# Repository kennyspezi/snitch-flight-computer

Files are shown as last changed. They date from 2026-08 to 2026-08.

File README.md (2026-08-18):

# Flight Compute Unit (FCU)
For future UAV and upcoming Omnimouse build (continuation of Micromouse)

## Schematics
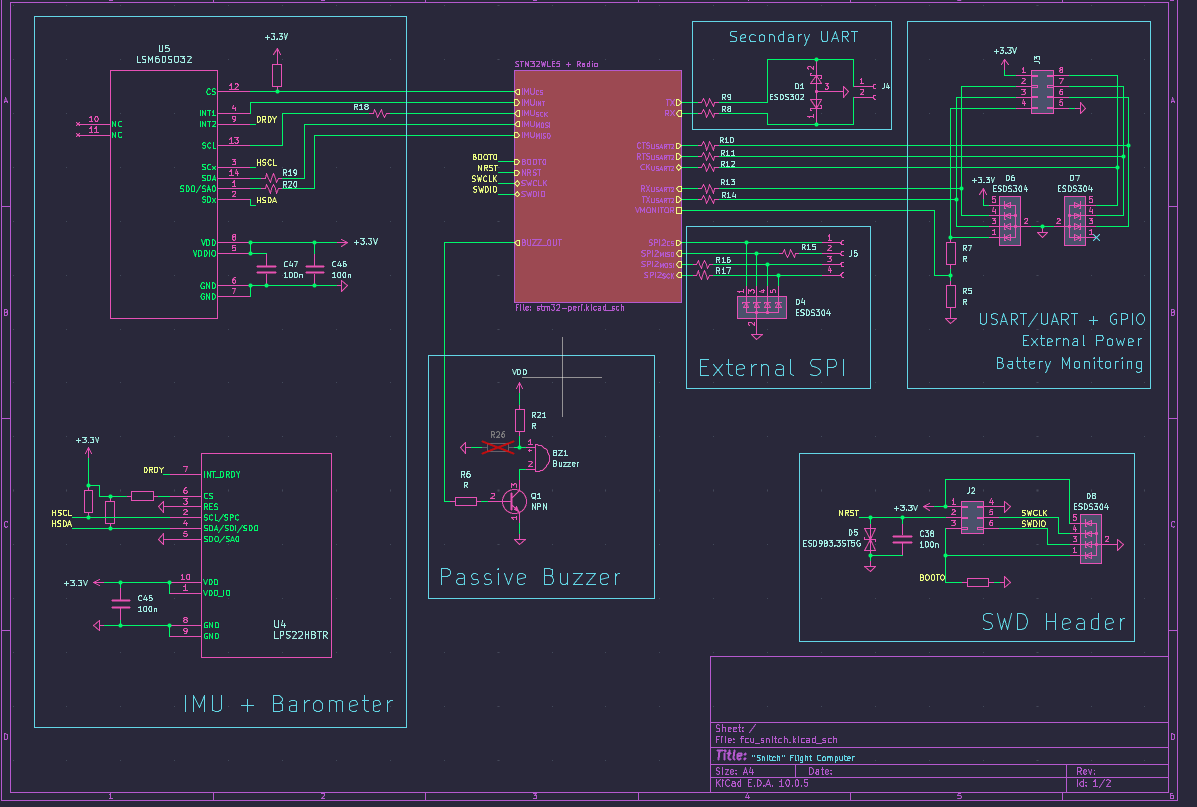
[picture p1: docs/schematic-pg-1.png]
Pg 1

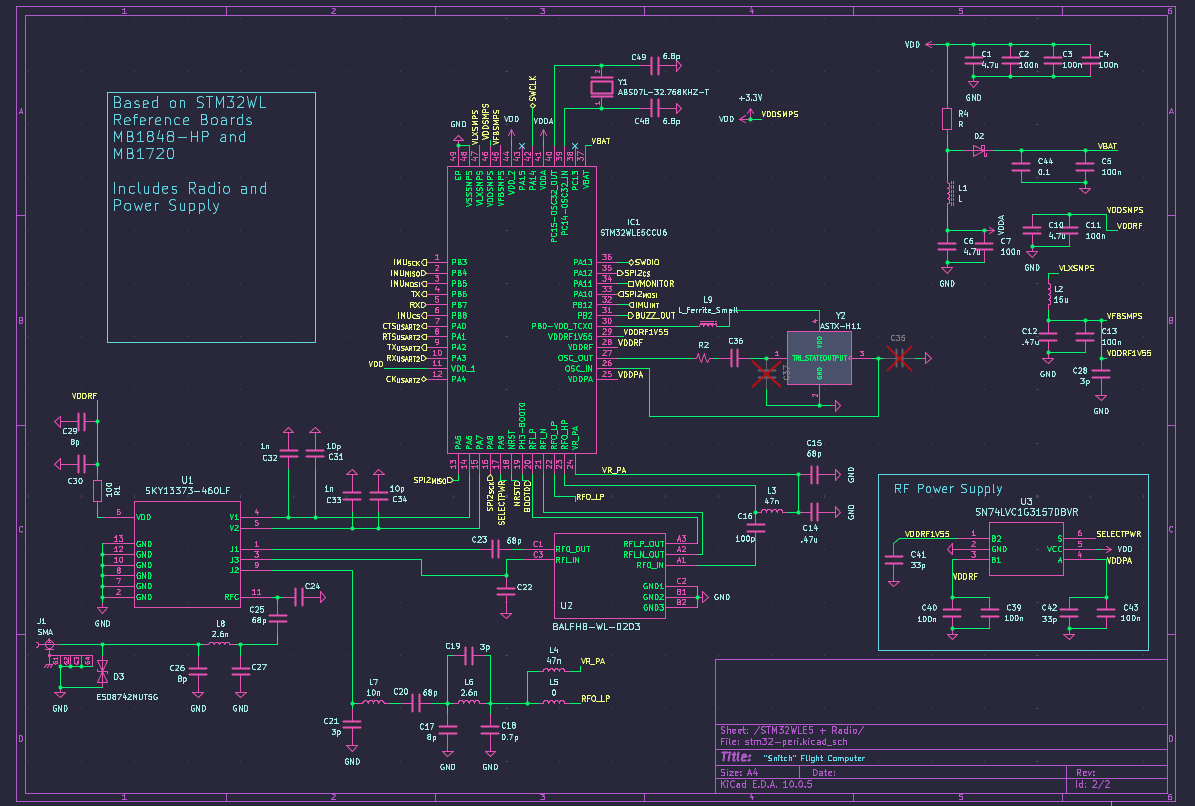
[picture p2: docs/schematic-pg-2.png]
Pg 2


## PCB (as of 08/18/2026)
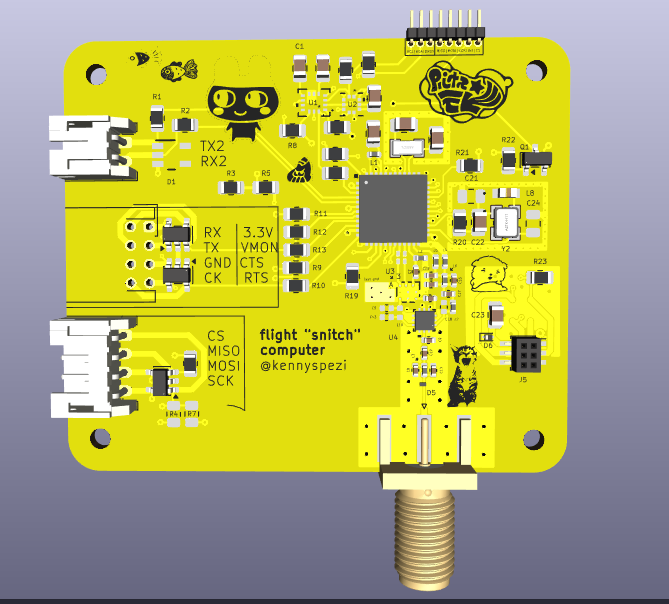
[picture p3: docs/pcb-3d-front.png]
3D Front

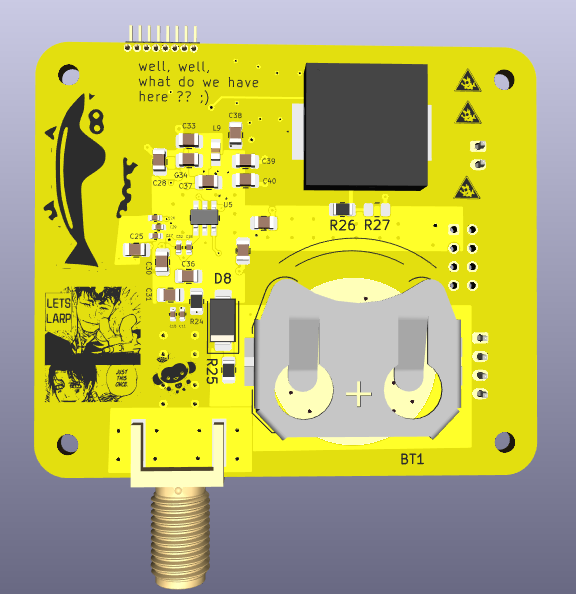
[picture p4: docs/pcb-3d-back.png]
3D Back


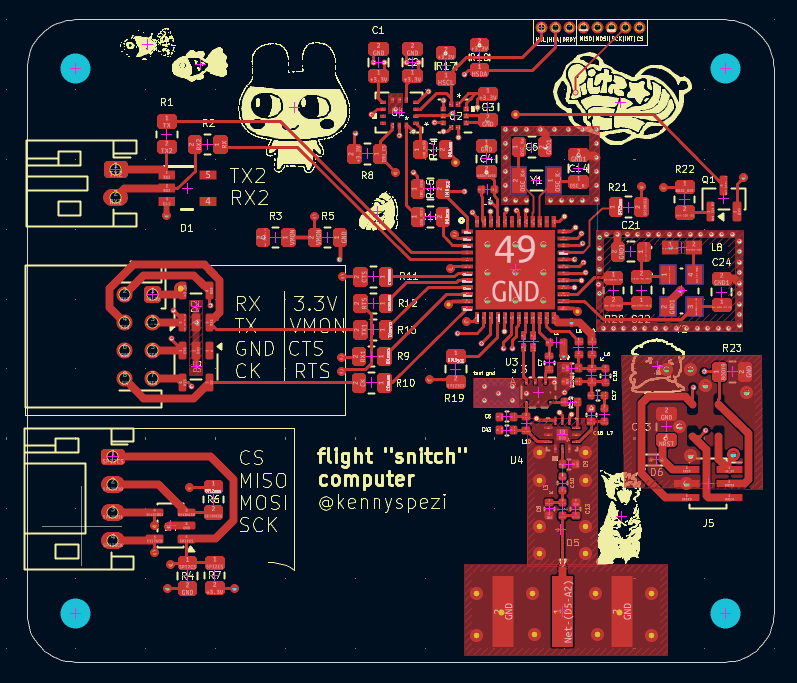
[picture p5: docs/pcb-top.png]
Top Layer

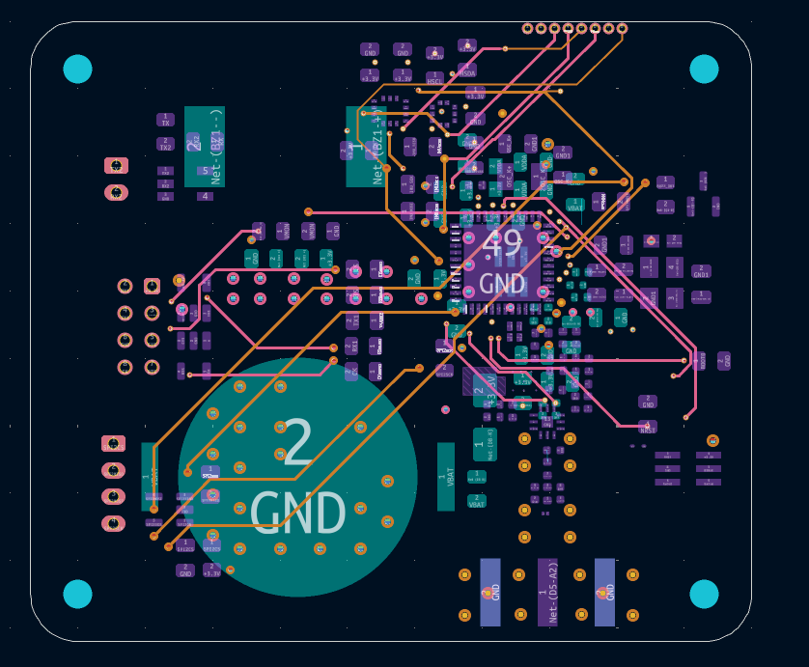
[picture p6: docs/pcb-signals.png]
Signals

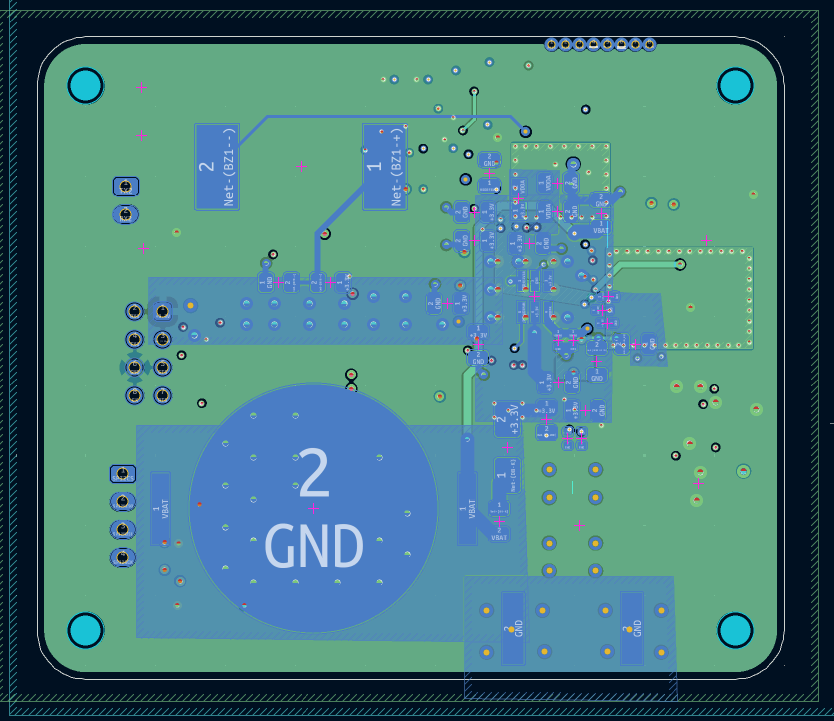
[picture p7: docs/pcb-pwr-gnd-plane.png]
Power + GND Distribution

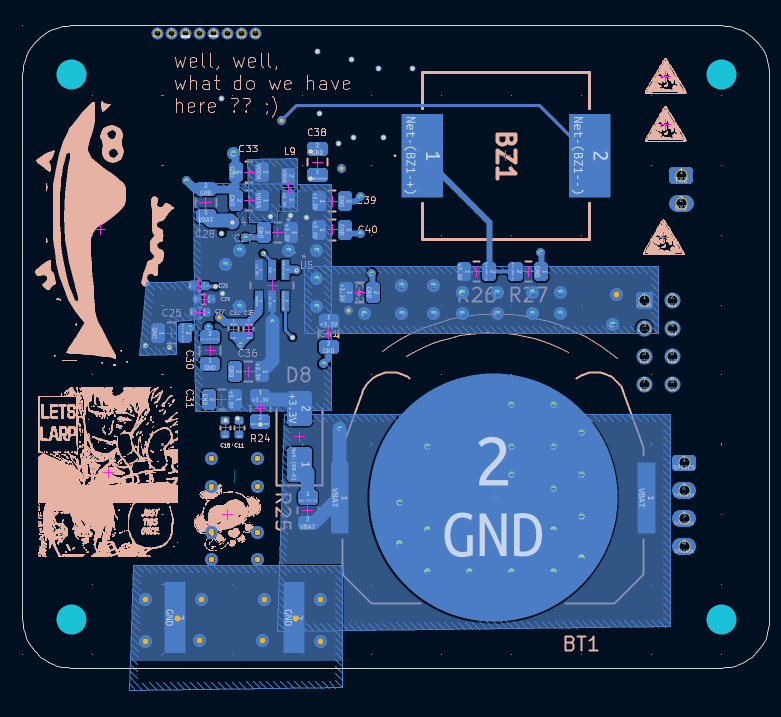
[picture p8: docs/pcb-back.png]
Bottom Layer


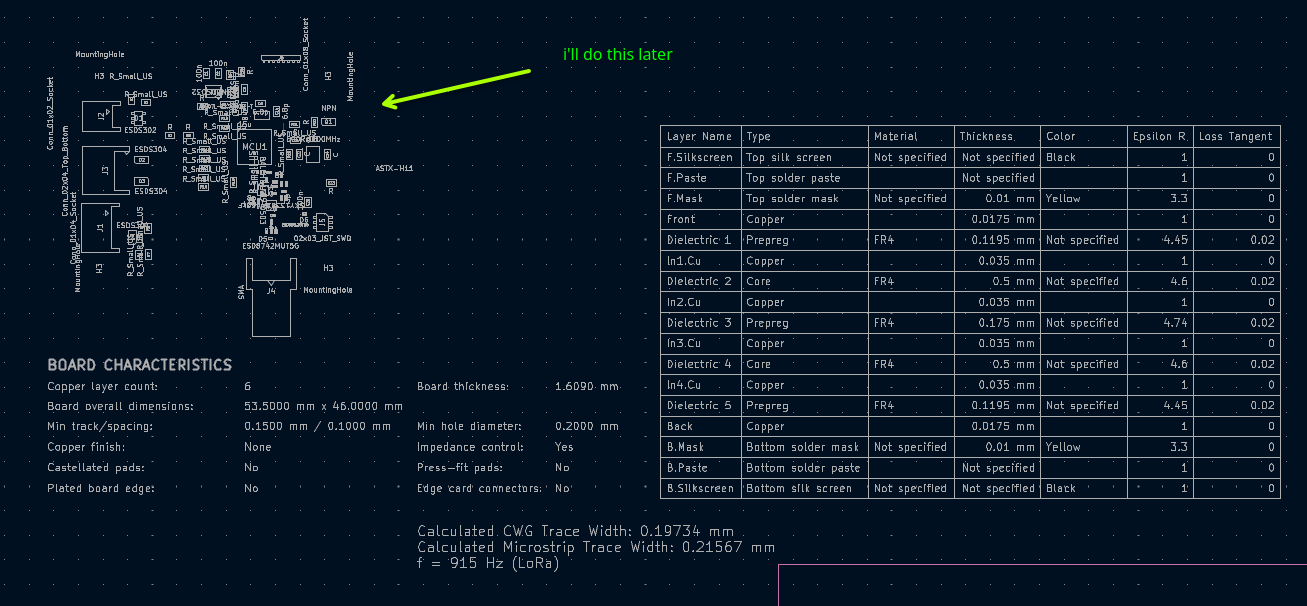
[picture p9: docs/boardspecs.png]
BoardSpecs


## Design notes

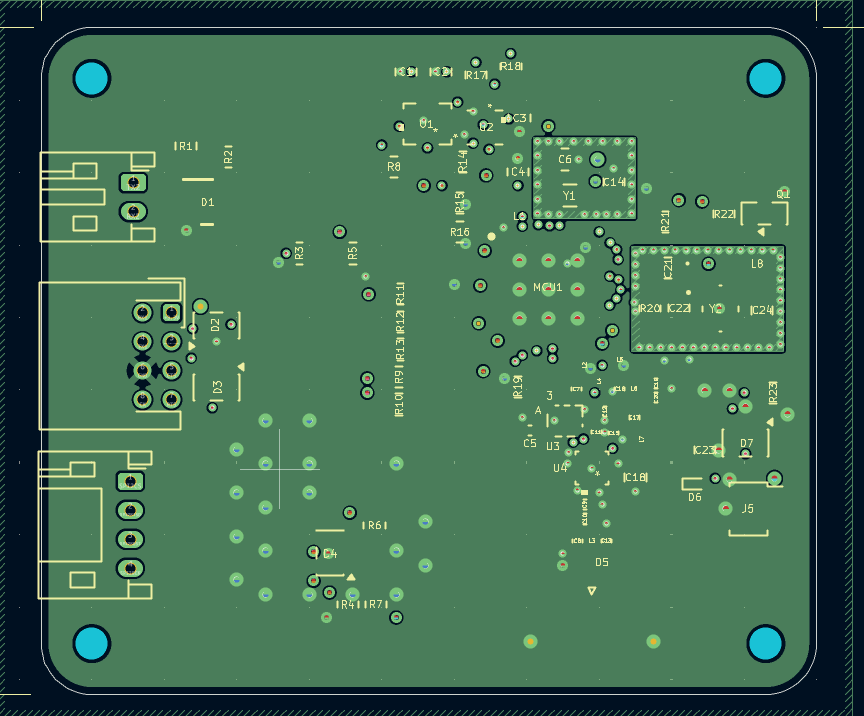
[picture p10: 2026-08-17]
docs/pcb-gnd.png

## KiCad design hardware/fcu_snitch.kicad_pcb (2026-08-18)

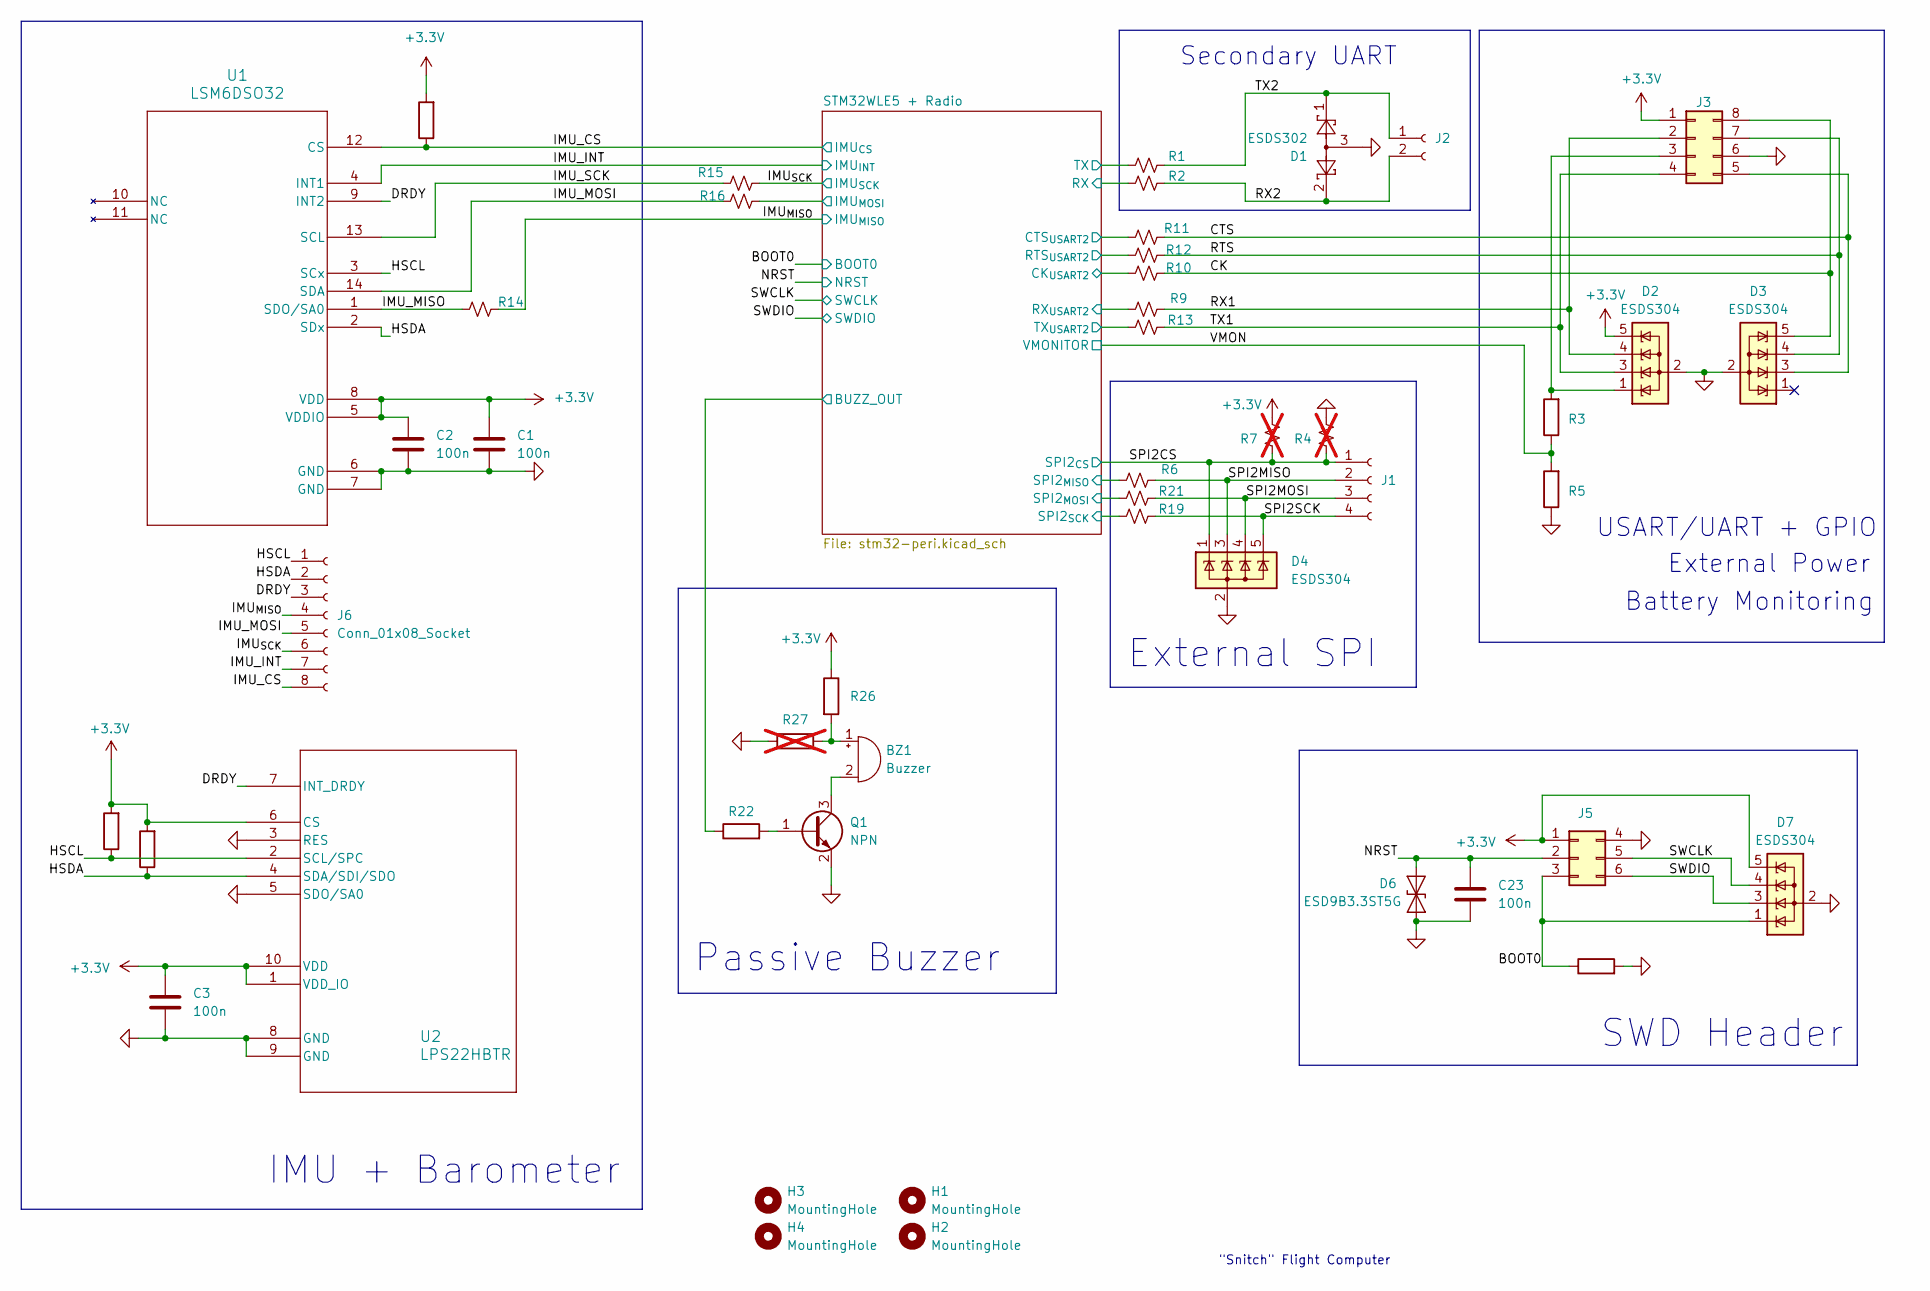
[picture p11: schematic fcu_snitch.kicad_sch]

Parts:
BZ1: Buzzer; CPT120303SMTTR
C1, C2, C3, C23: 100n; C_0805_2012Metric
D1: ESDS302; DBV0005A_M
D2, D3, D4, D7: ESDS304; SOT-23-5
D6: ESD9B3.3ST5G; D_SOD-923
H1, H2, H3, H4: MountingHole; MountingHole_2.2mm_M2
J1: Conn_01x04_Socket; JST_PH_S4B-PH-K_1x04_P2.00mm_Horizontal
J2: Conn_01x02_Socket; JST_PH_S2B-PH-K_1x02_P2.00mm_Horizontal
J3: Conn_02x04_Top_Bottom; JST_PHD_S8B-PHDSS_2x04_P2.00mm_Horizontal
J5: 02x03_JST_SWD; PinSocket_2x03_P1.00mm_Vertical_SMD
J6: Conn_01x08_Socket; PinHeader_1x08_P1.00mm_Horizontal
Q1: NPN; SOT-23
R1, R2, R6, R9, R10, R11, R12, R13, R14, R15, R16, R19, R21: R_Small_US; R_0805_2012Metric
R3, R5, R8, R17, R18, R22, R23, R26: R; R_0805_2012Metric
R4, R7: R_Small_US; R_0805_2012Metric; not fitted
R27: R; R_0805_2012Metric; not fitted
U1: LSM6DSO32; LGA-14L_2P5X3X0P83_STM-L
U2: LPS22HBTR; HLGA10_2X2_STM-L

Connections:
+3.3V: C1.1, C2.1, C3.1, D2.5 (K), D7.5 (K), J3.1, J5.1, R7.2, R8.2, R17.2, R18.2, R26.1, U1.5 (VDDIO), U1.8 (VDD), U2.1 (VDD_IO), U2.6 (CS), U2.10 (VDD); also elsewhere on the board
/BOOT0: D7.1 (K), J5.3, R23.1; also elsewhere on the board
/CK: D3.5 (K), J3.8, R10.2
/CTS: D3.3 (K), J3.5, R11.2
/DRDY: J6.3, U1.9 (INT2), U2.7 (INT_DRDY)
/HSCL: J6.1, R17.1, U1.3 (SCx), U2.2 (SCL/SPC)
/HSDA: J6.2, R18.1, U1.2 (SDx), U2.4 (SDA/SDI/SDO)
/IMU_CS: J6.8, R8.1, U1.12 (CS); also elsewhere on the board
/IMU_INT: J6.7, U1.4 (INT1); also elsewhere on the board
/IMU_MISO: R14.1, U1.1 (SDO/SA0)
/IMU_MOSI: J6.5, R16.1, U1.14 (SDA)
/IMU_SCK: R15.1, U1.13 (SCL)
/IMU_{MISO}: J6.4, R14.2; also elsewhere on the board
/IMU_{SCK}: J6.6, R15.2; also elsewhere on the board
/NRST: C23.1, D6.2 (A2), J5.2; also elsewhere on the board
/RTS: D3.4 (K), J3.7, R12.2
/RX1: D2.4 (K), J3.2, R9.2
/RX2: D1.2, J2.2, R2.2
/SPI2CS: D4.1 (K), J1.1, R4.1, R7.1; also elsewhere on the board
/SPI2MISO: D4.3 (K), J1.2, R6.2
/SPI2MOSI: D4.4 (K), J1.3, R21.2
/SPI2SCK: D4.5 (K), J1.4, R19.2
/STM32WLE5 + Radio/BUZZ_OUT: R22.1; also elsewhere on the board
/STM32WLE5 + Radio/CK_{USART2}: R10.1; also elsewhere on the board
/STM32WLE5 + Radio/CTS_{USART2}: R11.1; also elsewhere on the board
/STM32WLE5 + Radio/IMU_{MOSI}: R16.2; also elsewhere on the board
/STM32WLE5 + Radio/RTS_{USART2}: R12.1; also elsewhere on the board
/STM32WLE5 + Radio/RX: R2.1; also elsewhere on the board
/STM32WLE5 + Radio/RX_{USART2}: R9.1; also elsewhere on the board
/STM32WLE5 + Radio/SPI2_{MISO}: R6.1; also elsewhere on the board
/STM32WLE5 + Radio/SPI2_{MOSI}: R21.1; also elsewhere on the board
/STM32WLE5 + Radio/SPI2_{SCK}: R19.1; also elsewhere on the board
/STM32WLE5 + Radio/TX: R1.1; also elsewhere on the board
/STM32WLE5 + Radio/TX_{USART2}: R13.1; also elsewhere on the board
/SWCLK: D7.4 (K), J5.5; also elsewhere on the board
/SWDIO: D7.3 (K), J5.6; also elsewhere on the board
/TX1: D2.3 (K), J3.4, R13.2
/TX2: D1.1, J2.1, R1.2
/VMON: R3.1, R5.2; also elsewhere on the board
GND: C1.2, C2.2, C3.2, C23.2, D1.3, D2.2 (A), D3.2 (A), D4.2 (A), D6.1 (A1), D7.2 (A), J3.6, J5.4, Q1.2 (E), R4.2, R5.1, R23.2, R27.1, U1.6 (GND), U1.7 (GND), U2.3 (RES), U2.5 (SDO/SA0), U2.8 (GND), U2.9 (GND); also elsewhere on the board
unnamed: BZ1.1 (+), R26.2, R27.2
unnamed: BZ1.2 (-), Q1.3 (C)
unnamed: D2.1 (K), J3.3, R3.2
unnamed: Q1.1 (B), R22.2

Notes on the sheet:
External SPI
Secondary UART
Battery Monitoring
IMU + Barometer
USART/UART + GPIO
SWD Header
External Power
"Snitch" Flight Computer
Passive Buzzer

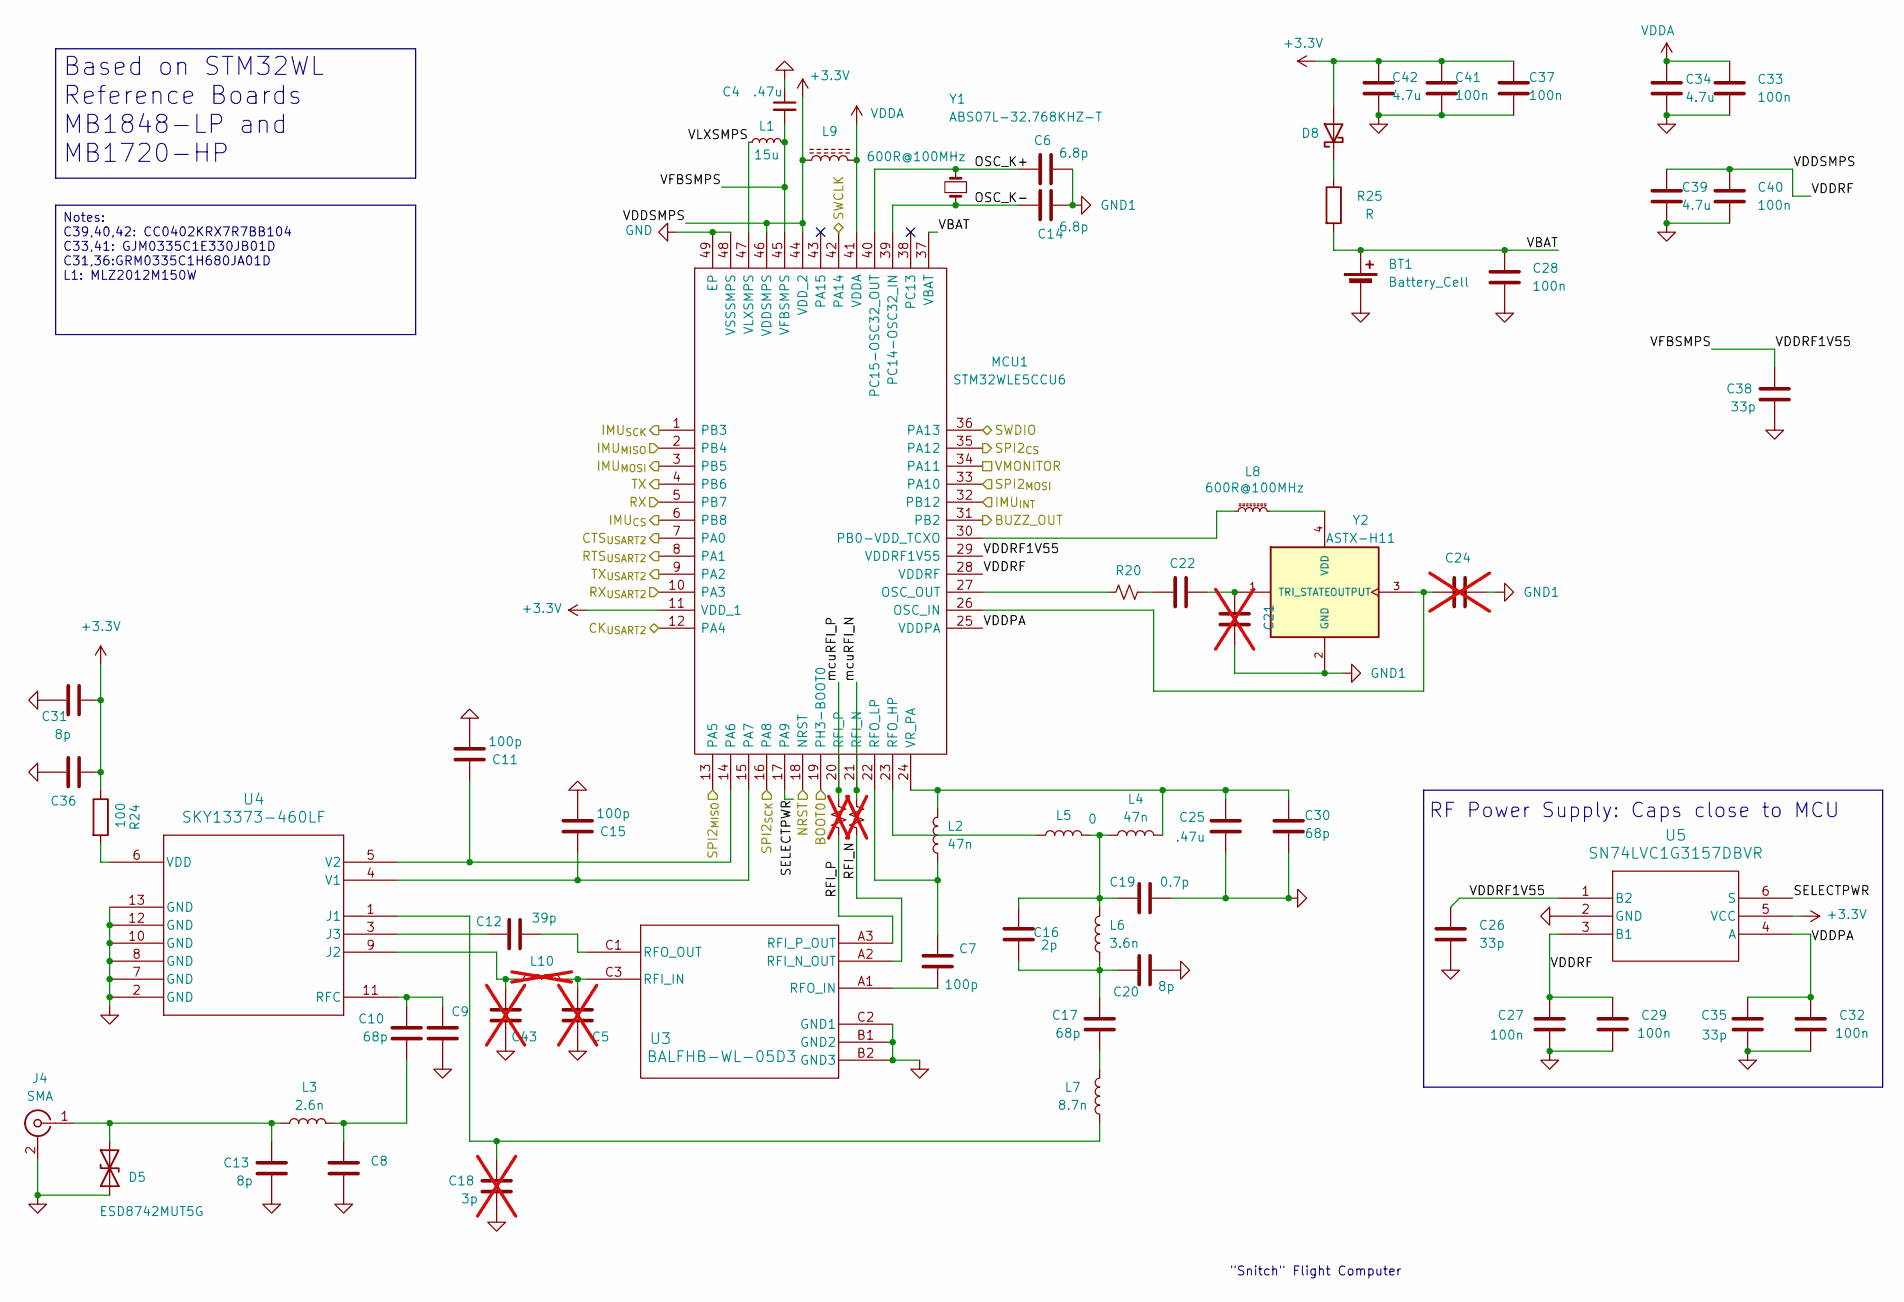
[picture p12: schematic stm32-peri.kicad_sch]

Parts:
BT1: Battery_Cell; BatteryHolder_Keystone_3034_1x20mm
C4, C25: .47u; C_0805_2012Metric
C5: 100p; C_0402_1005Metric; not fitted
C6, C14: 6.8p; C_0805_2012Metric
C7, C11, C15: 100p; C_0402_1005Metric
C8, C9: C_0402_1005Metric
C10, C17: 68p; C_0402_1005Metric
C12: 39p; C_0402_1005Metric
C13, C20: 8p; C_0402_1005Metric
C16: 2p; C_0402_1005Metric
C18: 3p; C_0402_1005Metric; not fitted
C19: 0.7p; C_0402_1005Metric
C21, C24: C; C_0805_2012Metric; not fitted
C22: C; C_0805_2012Metric
C26, C35: 33p; C_0402_1005Metric
C27, C29, C32: 100n; C_0402_1005Metric
C28, C33, C37, C40, C41: 100n; C_0805_2012Metric
C30: 68p; C_0805_2012Metric
C31: 8p; C_0805_2012Metric
C34, C39, C42: 4.7u; C_0805_2012Metric
C36: C_0805_2012Metric
C38: 33p; C_0805_2012Metric
C43: 8p; C_0402_1005Metric; not fitted
D5: ESD8742MUT5G; X3DFN2_ONS
D8: D_Schottky; D_SMA
J4: SMA; SMA_Amphenol_132289_EdgeMount
L1: 15u; L_0402_1005Metric
L2, L4: 47n; L_0402_1005Metric
L3: 2.6n; L_0402_1005Metric
L5: 0; L_0402_1005Metric
L6: 3.6n; L_0402_1005Metric
L7: 8.7n; L_0402_1005Metric
L8, L9: 600R@100MHz; IND_BLM18KG601SN1D_MUR-M
L10: 3.6n; L_0402_1005Metric; not fitted
MCU1: STM32WLE5CCU6; QFN50P700X700X60-49N-D; Mouser Part Number 511-STM32WLE5CCU6
R20: R_Small_US; R_0805_2012Metric
R24: 100; R_0805_2012Metric
R25: R; R_0805_2012Metric
R28, R29: R_Small_US; R_0201_0603Metric_Pad0.64x0.40mm_HandSolder; not fitted
U3: BALFHB-WL-05D3; BGA8_BALFHB_STM
U4: SKY13373-460LF; SKY13373-460LF_SKY
U5: SN74LVC1G3157DBVR; DBV6
Y1: ABS07L-32.768KHZ-T; XTAL_ABS07L-32.768KHZ-T; PARTREV 02.07.13
Y2: ASTX-H11; XTAL_ASTX-H11-32.000MHZ-I25-T; PARTREV 05.13.15

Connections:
+3.3V: C27.1, C29.1, C31.1, C36.1, C37.1, C39.1, C40.1, C41.1, C42.1, D8.2 (A), L9.1, MCU1.11 (VDD_1), MCU1.28 (VDDRF), MCU1.44 (VDD_2), MCU1.46 (VDDSMPS), R24.1, U5.3 (B1), U5.5 (VCC); also elsewhere on the board
/BOOT0: MCU1.19 (PH3-BOOT0); also elsewhere on the board
/IMU_CS: MCU1.6 (PB8); also elsewhere on the board
/IMU_INT: MCU1.32 (PB12); also elsewhere on the board
/IMU_{MISO}: MCU1.2 (PB4); also elsewhere on the board
/IMU_{SCK}: MCU1.1 (PB3); also elsewhere on the board
/NRST: MCU1.18 (NRST); also elsewhere on the board
/SPI2CS: MCU1.35 (PA12); also elsewhere on the board
/STM32WLE5 + Radio/BUZZ_OUT: MCU1.31 (PB2); also elsewhere on the board
/STM32WLE5 + Radio/CK_{USART2}: MCU1.12 (PA4); also elsewhere on the board
/STM32WLE5 + Radio/CTS_{USART2}: MCU1.7 (PA0); also elsewhere on the board
/STM32WLE5 + Radio/IMU_{MOSI}: MCU1.3 (PB5); also elsewhere on the board
/STM32WLE5 + Radio/OSC_K+: C6.1, MCU1.40 (PC15-OSC32_OUT), Y1.2
/STM32WLE5 + Radio/OSC_K-: C14.1, MCU1.39 (PC14-OSC32_IN), Y1.1
/STM32WLE5 + Radio/RFI_N: R29.2, U3.A2 (RFI_N_OUT)
/STM32WLE5 + Radio/RFI_P: R28.2, U3.A3 (RFI_P_OUT)
/STM32WLE5 + Radio/RTS_{USART2}: MCU1.8 (PA1); also elsewhere on the board
/STM32WLE5 + Radio/RX: MCU1.5 (PB7); also elsewhere on the board
/STM32WLE5 + Radio/RX_{USART2}: MCU1.10 (PA3); also elsewhere on the board
/STM32WLE5 + Radio/SELECTPWR: MCU1.17 (PA9), U5.6 (S)
/STM32WLE5 + Radio/SPI2_{MISO}: MCU1.13 (PA5); also elsewhere on the board
/STM32WLE5 + Radio/SPI2_{MOSI}: MCU1.33 (PA10); also elsewhere on the board
/STM32WLE5 + Radio/SPI2_{SCK}: MCU1.16 (PA8); also elsewhere on the board
/STM32WLE5 + Radio/TX: MCU1.4 (PB6); also elsewhere on the board
/STM32WLE5 + Radio/TX_{USART2}: MCU1.9 (PA2); also elsewhere on the board
/STM32WLE5 + Radio/VBAT: BT1.1 (+), C28.1, MCU1.37 (VBAT), R25.2
/STM32WLE5 + Radio/VDDPA: C32.1, C35.1, MCU1.25 (VDDPA), U5.4 (A)
/STM32WLE5 + Radio/VDDRF1V55: C4.2, C26.1, C38.1, L1.2, MCU1.29 (VDDRF1V55), MCU1.45 (VFBSMPS), U5.1 (B2)
/STM32WLE5 + Radio/VLXSMPS: L1.1, MCU1.47 (VLXSMPS)
/STM32WLE5 + Radio/mcuRFI_N: MCU1.21 (RFI_N), R29.1
/STM32WLE5 + Radio/mcuRFI_P: MCU1.20 (RFI_P), R28.1
/SWCLK: MCU1.42 (PA14); also elsewhere on the board
/SWDIO: MCU1.36 (PA13); also elsewhere on the board
/VMON: MCU1.34 (PA11); also elsewhere on the board
GND: BT1.2 (-), C4.1, C5.1, C8.2, C9.2, C11.2, C13.2, C15.2, C18.2, C19.2, C20.2, C25.1, C26.2, C27.2, C28.2, C29.2, C30.1, C31.2, C32.2, C33.2, C34.2, C35.2, C36.2, C37.2, C38.2, C39.2, C40.2, C41.2, C42.2, C43.2, D5.1 (A1), J4.2 (Ext), MCU1.48 (VSSSMPS), MCU1.49 (EP), U3.B1 (GND2), U3.B2 (GND3), U3.C2 (GND1), U4.2 (GND), U4.7 (GND), U4.8 (GND), U4.10 (GND), U4.12 (GND), U4.13 (GND), U5.2 (GND); also elsewhere on the board
GND1: C6.2, C14.2, C21.2, C24.2, Y2.2 (GND)
unnamed: C8.1, C10.2, L3.2
unnamed: C16.1, C17.2, C20.1, L6.1
unnamed: C16.2, C19.1, L4.2, L5.2, L6.2
unnamed: C17.1, L7.2
unnamed: C22.1, R20.2
unnamed: C13.1, D5.2 (A2), J4.1 (In), L3.1
unnamed: D8.1 (K), R25.1
unnamed: C24.1, MCU1.26 (OSC_IN), Y2.3 (OUTPUT)
unnamed: MCU1.27 (OSC_OUT), R20.1
unnamed: C11.1, MCU1.14 (PA6), U4.5 (V2)
unnamed: C15.1, MCU1.15 (PA7), U4.4 (V1)
unnamed: L8.1, MCU1.30 (PB0-VDD_TCXO)
unnamed: L5.1, MCU1.23 (RFO_HP)
unnamed: C7.2, L2.2, MCU1.22 (RFO_LP)
unnamed: C25.2, C30.2, L2.1, L4.1, MCU1.24 (VR_PA)
unnamed: C5.2, L10.2, U3.C3 (RFI_IN)
unnamed: C7.1, U3.A1 (RFO_IN)
unnamed: C12.1, U3.C1 (RFO_OUT)
unnamed: C18.1, L7.1, U4.1 (J1)
unnamed: C43.1, L10.1, U4.9 (J2)
unnamed: C12.2, U4.3 (J3)
unnamed: C9.1, C10.1, U4.11 (RFC)
unnamed: R24.2, U4.6 (VDD)
unnamed: C21.1, C22.2, Y2.1 (TRI_STATE)
unnamed: L8.2, Y2.4 (VDD)
VDDA: C33.1, C34.1, L9.2, MCU1.41 (VDDA)

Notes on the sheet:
"Snitch" Flight Computer
RF Power Supply: Caps close to MCU
Based on STM32WL Reference Boards MB1848-LP and MB1720-HP
Notes: C39,40,42: CC0402KRX7R7BB104 C33,41: GJM0335C1E330JB01D C31,36:GRM0335C1H680JA01D L1: MLZ2012M150W

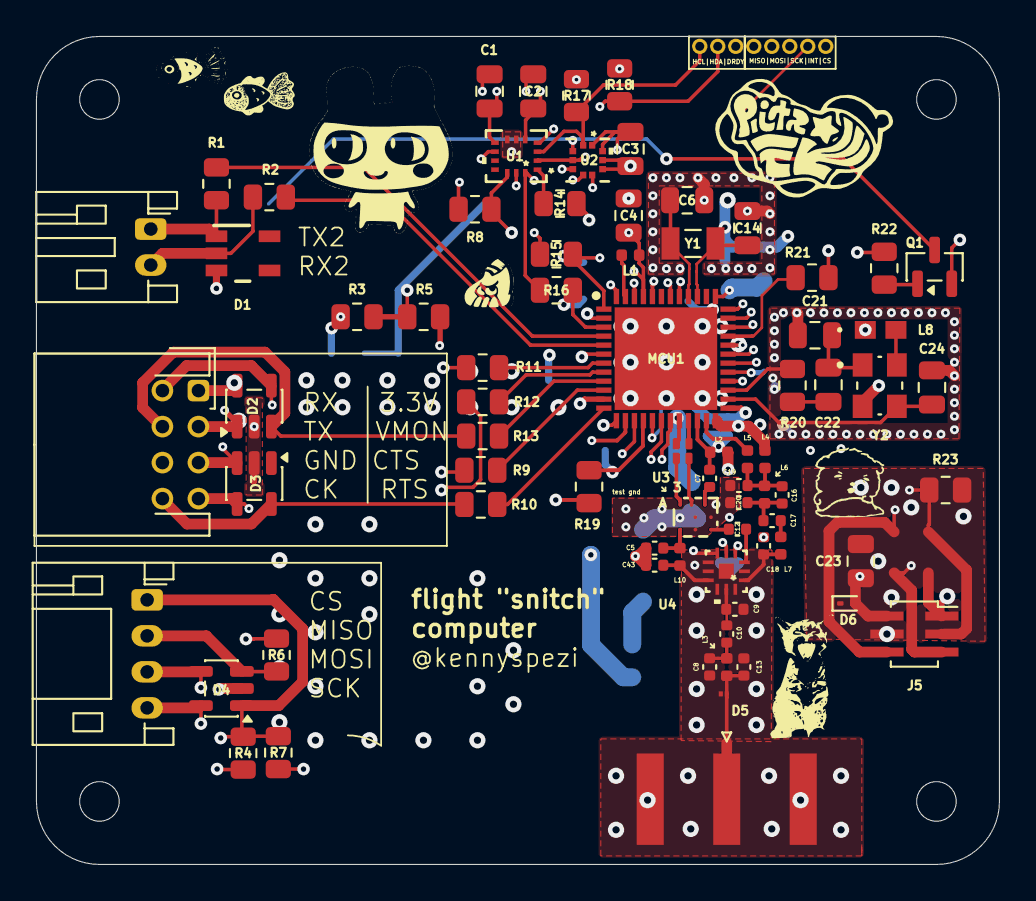
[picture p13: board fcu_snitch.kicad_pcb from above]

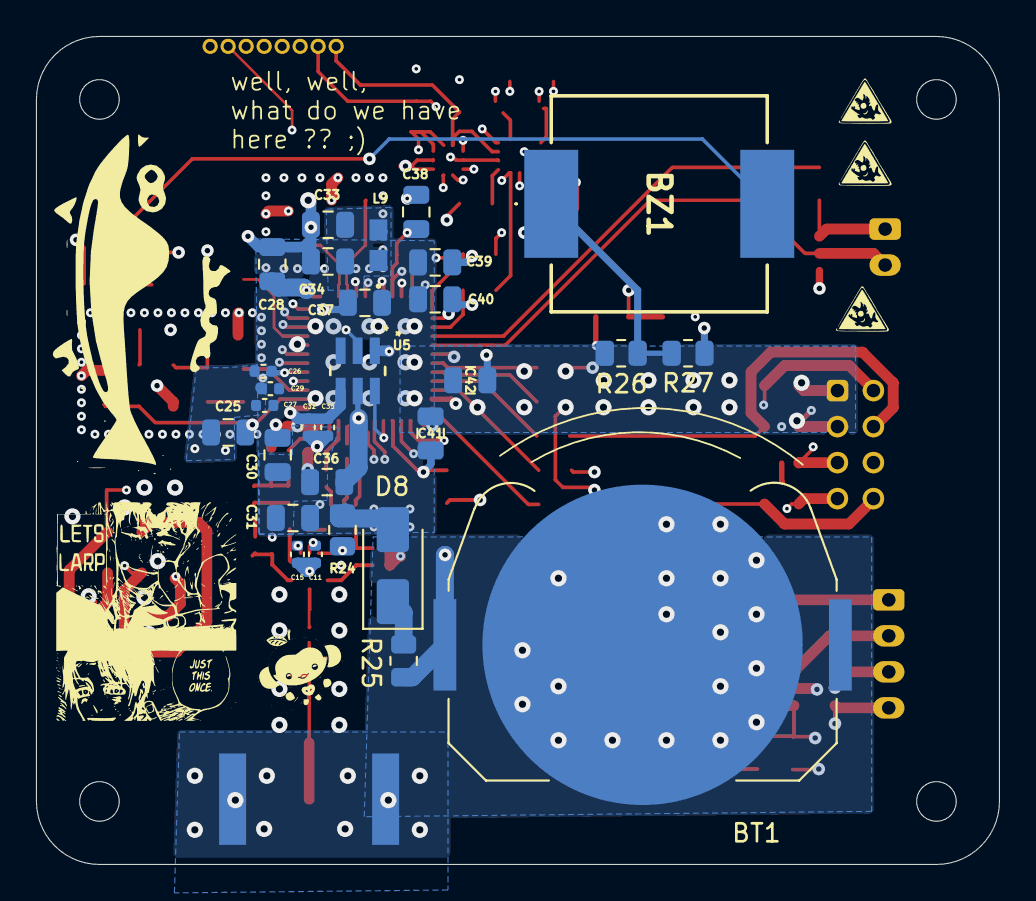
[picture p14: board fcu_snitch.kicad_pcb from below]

Board: 6 copper layers, 53.5 x 46.0 mm, 113 parts (29 on the bottom side), 82 nets.

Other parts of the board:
H3#2, H3#3, H3#4: MountingHole; MountingHole_2.2mm_M2

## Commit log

2026-08-07 first commit: schematic and footprints for every part
    [fcu_snitch.kicad_pcb, fcu_snitch.kicad_sch, stm32-peri.kicad_sch]
2026-08-15 schematic update and pcb route v1
    [fcu_snitch.kicad_pcb, fcu_snitch.kicad_sch, stm32-peri.kicad_sch]
2026-08-17 better pcb route (no test pads)
    [fcu_snitch.kicad_pcb, fcu_snitch.kicad_sch, stm32-peri.kicad_sch]
2026-08-18 pcb v2 update: test points, stickers, labeling
    [fcu_snitch.kicad_pcb, fcu_snitch.kicad_sch, stm32-peri.kicad_sch]
